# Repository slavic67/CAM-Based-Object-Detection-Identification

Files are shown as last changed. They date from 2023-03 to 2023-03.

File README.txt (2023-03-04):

# CAM Based Object Detection & Identification

* * *
Включает в себя направления:
1. Электроника
	1. Необходима принципиальная схема подключения драйверов шаговых двигателей к МК ATMEGA. Найти шаговые двигатели, драйвера, написать код на Си, отладить (возможно стоит добавить концевики). 
	2. Необходима принципиальная схема подводимых каналов питания. Делать несколько раздельных линий или одну, но ветвить через LDO.
3. Конструкторская часть - SolidWorks, 3D печать
	1. Спроектировать корпус изделия, подставки, на которых вращаются шаговые двигатели, крепление для камеры и лазерной указки.
	2. Напечатать конструкцию, собрать, довести до рабочего состояния.
5. Программирование - Си
	1. Необходим командный интерфейс - по com-порту подается команда какой двигатель на сколько шагов и в какую сторону повернуть. Отработать ошибки ввода.
	2. Возможно добавить поворот камеры. Если устанавливать концевики, то включить их в алгоритм принятия решения о повороте.
7. Программирование - Python
	1. Научиться находить и автоматически идентифицировать простые фигуры на картинке - шар, квадрат. Использовать алгоритмы на нейросетях - openCV, Tensorflow.
	3. Написать программный ПИД-регулятор, чтобы быстро и плавно наводить указку на необходимый объект.
	4. Дополнительно распознавать код лазерной указки (мигание с заданной частотой) на видео. Вести одновременно несколько целей (используя несколько указок).
* * *
Цель научно исследовательской работы:
С помощью камеры детектировать и идентифицировать объекты с последующим лазерным наведением на него. Всё управление производится с ПК. 
* * *
Задачи научно исследовательской работы:
1. Найти необходиимые компоненты:
	1. шаговые двигатели
	2. камера
	3. драйверы шаговых двигателей
	4. плата управления
	6. подшипники
	7. лазерная указка до 5 мВт
	8. концевики
2. Разработать модель корпуса в SOLIDWORKS
3. Разработать принципиальную схему устройства
4. Написать софт на Си для управления шаговыми двигателями
5. Научиться распознавать и идентифицировать объекты на видео
6. Написать софт на Python для полного управления системой
7. Продемонстрировать детектирование статичного объекта
8. Продемонстрировать детектирование динамического объекта
9. Продемонстрировать распознавание лазерного кода на видео
10. Продемонстрировать детектирование нескольких динамических объектов
* * *
Тактико-технические характеристики (ТТХ):
1. Наведение лазерного луча мощностью не более 5 мВт на центр объекта с точностью не менее 10 см.
3. Дальность обнаружения и наведения не более 10 м.
4. Скорость обнаружения и наведения на статичный объект не более 3 сек.
5. Ведение цели (обьекта) лазерным лучом со скоростью не менее 1 м\с.
6. Максимальная потребляемая мощность 24 Вт.
* * *
Дополнительно:
1. Реализовать работу в условиях отсутствия освещенности. Применить инфракрасную подсветку.
3. Реализовать обработку исключительных ситуаций: совмещение целей друг за другом, экстренное отключение лазерного луча при случайном наведение на глаза.
4. Реализовать наведение независимо от положения камеры. Лазерный луч может быть вне объектива камеры.
* * *
Материально-техническое обеспечение:
1. шаговые двигатели, 2 шт.
2. лазерный модуль мощностью 5 мВт, 1 шт.
3. ПК
4. Веб камера (не самая дешевая) full-HD
5. Плата управления драйверов шаговых двигателей с наличием USB-UART преобразователем для связи с ПК (подходит ARDUINO UNO)
6. программатор для микроконтроллеров AVR на базе ISP500, для программирования через среду AVR STUDIO
7. Драйвер шагового двигателя A4988, 2 шт.
8. Шаговый двигатель Nema17 (17HS4023), 2 шт.
9. Лазерный модуль 5 мВт. Рисунок - точка. Цвет - красный.
10. Модуль с транзисторным ключом для управление лазерным модулем. 
11. Блок питания DC 12 В, 2 А
12. Доступ к 3D принтеру для печати узлов механики, смоделированных в SolidWorks
13. Мелочи в виде подшипников, штырьевых проводов и т.п.
* все кроме камеры и ноутбука следует закупить минимум на два комплекта.
* * *

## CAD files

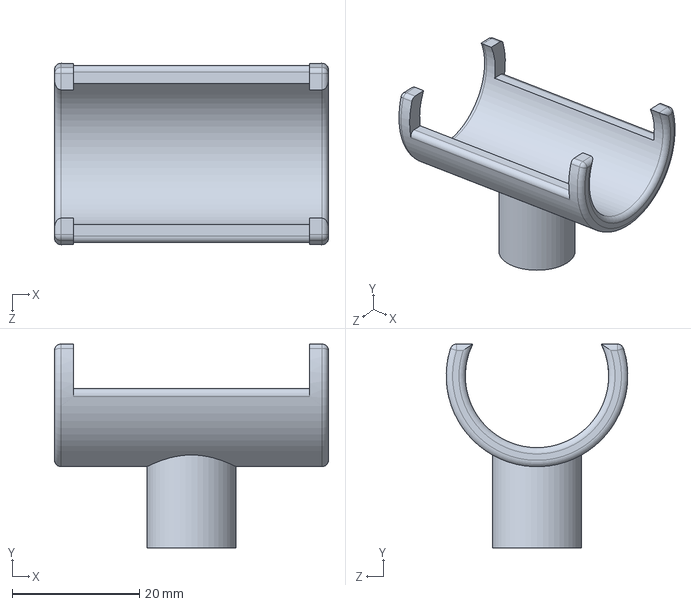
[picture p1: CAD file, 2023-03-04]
construction/переходник для лазера.SLDPRT
43.0 x 32.0 x 28.5 mm

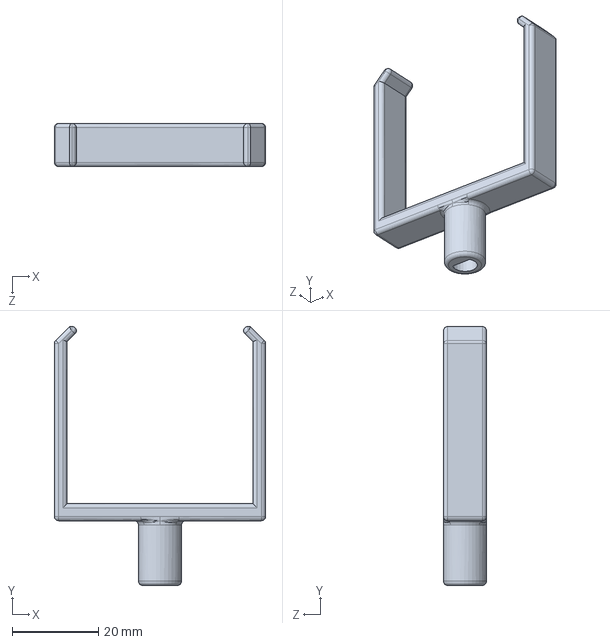
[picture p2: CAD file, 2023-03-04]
construction/переходник.SLDPRT
49.0 x 60.0 x 10.0 mm

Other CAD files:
construction/переходник для лазера.STL
construction/переходник.STL

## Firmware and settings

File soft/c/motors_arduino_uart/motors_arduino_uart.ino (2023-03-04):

#include <Arduino_FreeRTOS.h>
#include <semphr.h>
#include <stdbool.h>

#define frequency 1000

void turn_installation1();
void turn_installation2();

int installation1_arr[6]={0};
int installation2_arr[6]={0};


//configure first installation
struct FisrtInstallation
{
const uint8_t STEP_PIN1=2;
const uint8_t DIR_PIN1=3;
const uint8_t STEP_PIN2=4;
const uint8_t DIR_PIN2=5;
const uint8_t ms1_1mot_pin=8;
const uint8_t ms1_2mot_pin=9;
};

struct SecondInstallation
{
const uint8_t STEP_PIN1=22;
const uint8_t DIR_PIN1=24;
const uint8_t STEP_PIN2=26;
const uint8_t DIR_PIN2=28;
const uint8_t ms1_1mot_pin=30;
const uint8_t ms1_2mot_pin=32;
};

struct FisrtInstallation inst1;
struct SecondInstallation inst2;

void setup()
{
  Serial.begin(115200);

  //configure first installation
  pinMode(inst1.STEP_PIN1,OUTPUT);
  pinMode(inst1.DIR_PIN1,OUTPUT);
  pinMode(inst1.STEP_PIN2,OUTPUT);
  pinMode(inst1.DIR_PIN2,OUTPUT);
  pinMode(inst1.ms1_1mot_pin,OUTPUT);
  digitalWrite(inst1.ms1_1mot_pin,HIGH);
  pinMode(inst1.ms1_2mot_pin,OUTPUT);
  digitalWrite(inst1.ms1_2mot_pin,HIGH);
  //configure second installation
  pinMode(inst2.STEP_PIN1,OUTPUT);
  pinMode(inst2.DIR_PIN1,OUTPUT);
  pinMode(inst2.STEP_PIN2,OUTPUT);
  pinMode(inst2.DIR_PIN2,OUTPUT);
  pinMode(inst2.ms1_1mot_pin,OUTPUT);
  digitalWrite(inst2.ms1_1mot_pin,HIGH);
  pinMode(inst2.ms1_2mot_pin,OUTPUT);
  digitalWrite(inst2.ms1_2mot_pin,HIGH); 
}

void loop()
{
  if (Serial.available() > 0) 
    {
      String str=Serial.readStringUntil('\0');
      int signals[7]={0};
      
      Convert_to_int(str,signals);
      if (signals[0]==1)
        {
          //Serial.print("1");
          for  (int i=0;i<6;i++) installation1_arr[i]=signals[i+1];
          xTaskCreate(turn_installation1,"installation1",1024, NULL,5,NULL);
          
        }
      if (signals[0]==2)
        {
          //Serial.print("2");         
          for  (int i=0;i<6;i++) installation2_arr[i]=signals[i+1];
          xTaskCreate(turn_installation2,"installation1",1024, NULL,5,NULL);
        }
      
      
    }
}

void Convert_to_int(String str,int *intarr)
{
String number="";
    int j=0;
    for (int i=0;str[i]!='\0';i++)
    {
      if (str[i]==';')
      {
        intarr[j]=atoi(number.c_str());
        j++;
        number="";
      }
      else
      {
        number=number+str[i];
      }
    }
    intarr[j]=atoi(number.c_str());  
  }


void turn_installation1(void *pvParameters)
{
      digitalWrite(inst1.DIR_PIN1,installation1_arr[2]);       //code for two motors
      digitalWrite(inst1.DIR_PIN2,installation1_arr[5]);
      while (installation1_arr[1]>0||installation1_arr[4]>0)
        {
          if (installation1_arr[1]>0) digitalWrite(inst1.STEP_PIN1,HIGH);
          if (installation1_arr[4]>0) digitalWrite(inst1.STEP_PIN2,HIGH);
          delayMicroseconds(frequency);
          digitalWrite(inst1.STEP_PIN1,LOW);
          digitalWrite(inst1.STEP_PIN2,LOW);
          installation1_arr[1]--;
          installation1_arr[4]--;
          delayMicroseconds(frequency);
        } 
      Serial.print('1');
}

void turn_installation2(void *pvParameters)
{
    digitalWrite(inst2.DIR_PIN1,installation2_arr[2]);       
    digitalWrite(inst2.DIR_PIN2,installation2_arr[5]);
    while (installation2_arr[1]>0||installation2_arr[4]>0)
      {
        if (installation2_arr[1]>0) digitalWrite(inst2.STEP_PIN1,HIGH);
        if (installation2_arr[4]>0) digitalWrite(inst2.STEP_PIN2,HIGH);
        delayMicroseconds(frequency);
        digitalWrite(inst2.STEP_PIN1,LOW);
        digitalWrite(inst2.STEP_PIN2,LOW);
        installation2_arr[1]--;
        installation2_arr[4]--;
        delayMicroseconds(frequency);
      } 
    Serial.print('2');
}

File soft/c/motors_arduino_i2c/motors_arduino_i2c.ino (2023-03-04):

#include  <Wire.h>
#define frequency 2000
#define STEP_PIN1 2
#define DIR_PIN1 3
#define STEP_PIN2 4
#define DIR_PIN2 5
#define ms1_1mot_pin 8
#define ms1_2mot_pin 9 

int SLAVE_ADDRESS=0x04;
int ledPin=13;
int analogPin=A0;
boolean ledOn=false;

//-----------------------------
void write_data(int a,int b,int c)//выводит принятые данные
{
    Serial.println(a);
    Serial.println(b);
    Serial.println(c);  
}
//----------------------------
void toggleLED() //меняет состояние встроенного пина
{
  ledOn=!ledOn;
  digitalWrite(ledPin,ledOn);
  
 }
//---------------------------
void sendAnalogReading() //отправляет данные с аналогового входа
{
  int reading=analogRead(analogPin);
  Wire.write(reading>>2); //отправляем данные , для пирмера читал аналаговый вход
  }
//----------------------------------
void rmotor(int motor,int steps,int dir)
{
  if (motor==1){
digitalWrite(DIR_PIN1,dir);
 for (int i=0;i<steps;i++) {
  digitalWrite(STEP_PIN1,HIGH);
  delayMicroseconds(frequency);
  digitalWrite(STEP_PIN1,LOW);
  }}

if (motor==2){
digitalWrite(DIR_PIN2,dir);
 for (int i=0;i<steps;i++) {
  digitalWrite(STEP_PIN2,HIGH);
  delayMicroseconds(frequency);
  digitalWrite(STEP_PIN2,LOW);
  }
  }
}
//------------------------------
void rmotors(int motor1,int steps1,int dir1,int motor2,int steps2,int dir2)
{
  digitalWrite(DIR_PIN1,dir1);       //code for two motors
  digitalWrite(DIR_PIN2,dir2);
  while (steps1>0||steps2>0)
  {
    if (steps1>0) digitalWrite(STEP_PIN1,HIGH);
    if (steps2>0) digitalWrite(STEP_PIN2,HIGH);
    delayMicroseconds(frequency);
    digitalWrite(STEP_PIN1,LOW);
    digitalWrite(STEP_PIN2,LOW);
    steps1--;
    steps2--;
  }
}

  

void setup() {
  // put your setup code here, to run once:
pinMode(ledPin,OUTPUT);
Wire.begin(SLAVE_ADDRESS);//задаем адресс ведомого устройства
Wire.onReceive(processMessage);//функция которая вызывается при посткплении данных от мастера
Wire.onRequest(sendAnalogReading);//функция которая вызывается при получении запросов от мастера
Serial.begin(9600);
pinMode(STEP_PIN1,OUTPUT);
pinMode(DIR_PIN1,OUTPUT);
pinMode(STEP_PIN2,OUTPUT);
pinMode(DIR_PIN2,OUTPUT);
pinMode(ms1_1mot_pin,OUTPUT);
digitalWrite(ms1_1mot_pin,HIGH);
pinMode(ms1_2mot_pin,OUTPUT);
digitalWrite(ms1_2mot_pin,HIGH);
}

void loop() {}



void processMessage(int n)
{  
  /*
   int a,b,c;
   
   a=Wire.read();
   b=Wire.read();
   c=Wire.read();
   
   write_data(a,b,c);
   rmotor(a,b,c);
   toggleLED();
   */
   int motor1,steps1,dir1,motor2,steps2,dir2;
   motor1=Wire.read();
   steps1=Wire.read();
   dir1=Wire.read();
   motor2=Wire.read();
   steps2=Wire.read();
   dir2=Wire.read();
   toggleLED();
   rmotors(motor1,steps1,dir1,motor2,steps2,dir2);

}
